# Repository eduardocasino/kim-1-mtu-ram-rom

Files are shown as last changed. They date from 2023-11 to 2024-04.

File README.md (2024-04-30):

# KIM-1 RAM/ROM Expansion Board for the MTU Backplane

## **WARNING**

**ALTHOUGH THE REV. 3 SEEMS TO BE WORKING SO FAR, IT STILL NEEDS MORE TESTING. USE AT YOUR OWN RISK!!!**

If you ordered the first or second revision PCB, please see the "Rev. 1 Fix" and/or "Rev. 2 Fix" sections below.

## About

This is a highly configurable RAM/ROM expansion for MTU backplanes, like the one in the original K-1005 card file, my [expansion card](https://github.com/eduardocasino/kim-1-mtu-expansion-card) or my buffered motherboard.

WARNING: This design has not been tested yet. Use at your own risk!

## Characteristics

* Switchable 0000-03FF systen RAM replacement
* Switchable 0400-13FF RAM
* Switchable system ROM replacement (needs a small modification to the MTU boards to disable the DECEN line)
* 4 selectable ROM sets
* Enough room to place a ZIF socket for the ROM
* Switchable 4K RAM/ROM areas from 2000 to FFFF
* Configurable interrupt vectors to the top of any of the 4K chunks.
* Max. 1 TTL load on the bus, so it will work nicely on unbuffered backplanes

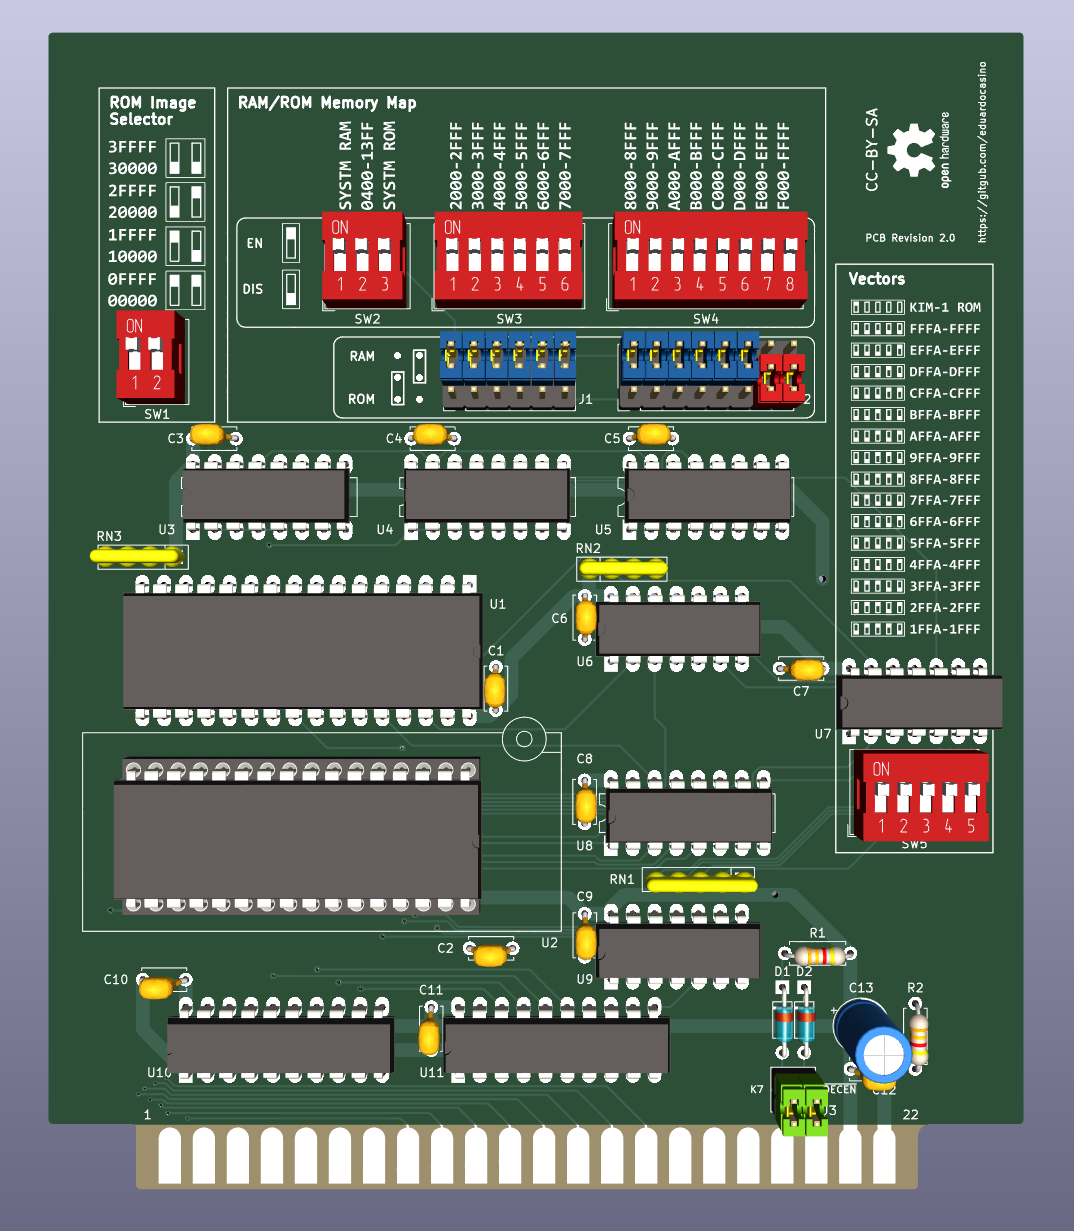
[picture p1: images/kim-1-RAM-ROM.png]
components

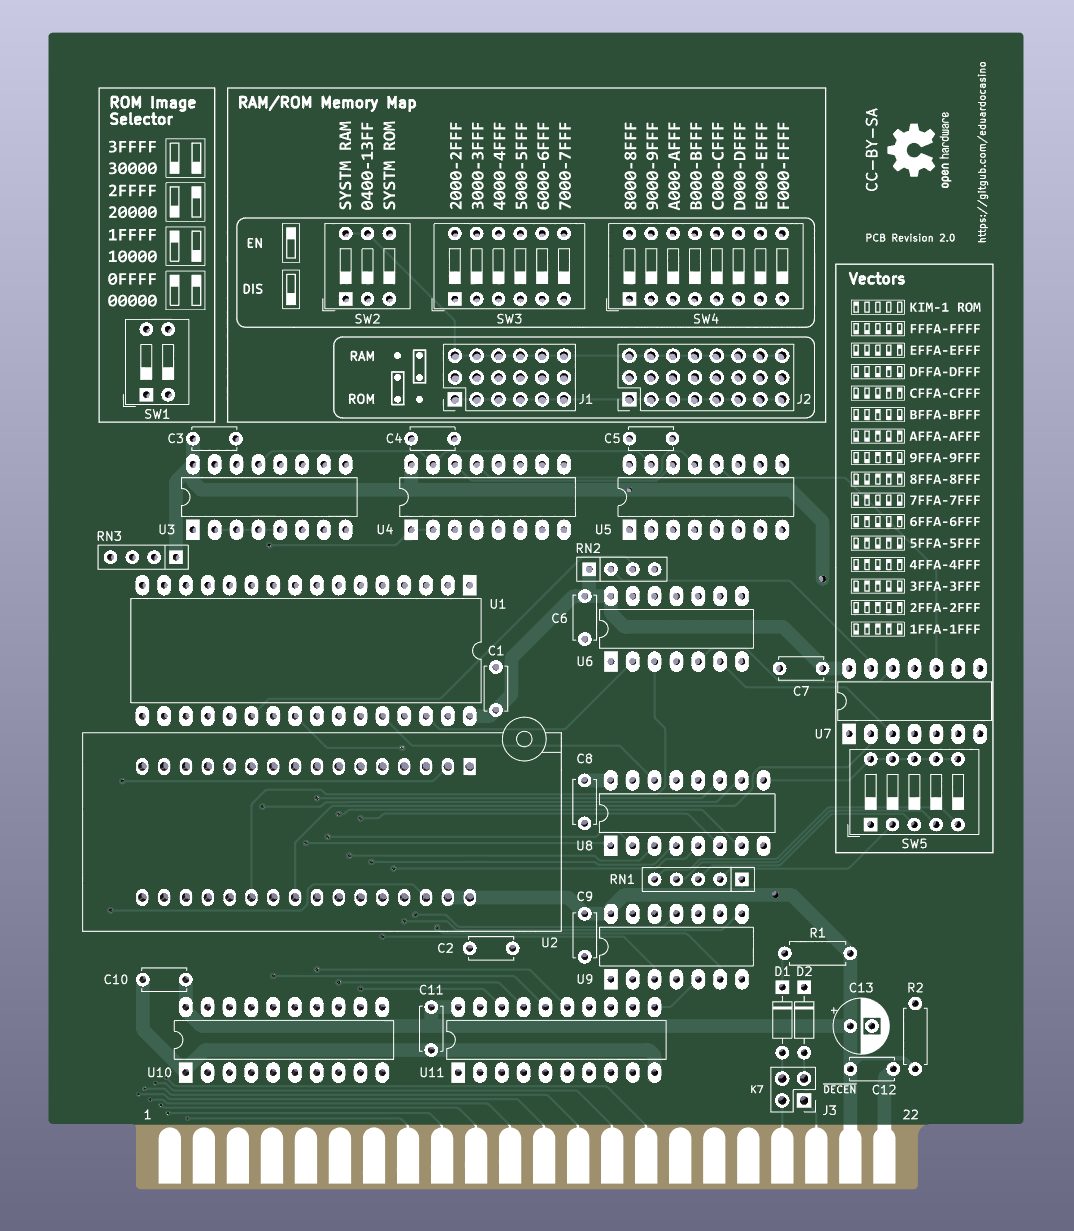
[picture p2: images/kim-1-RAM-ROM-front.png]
front

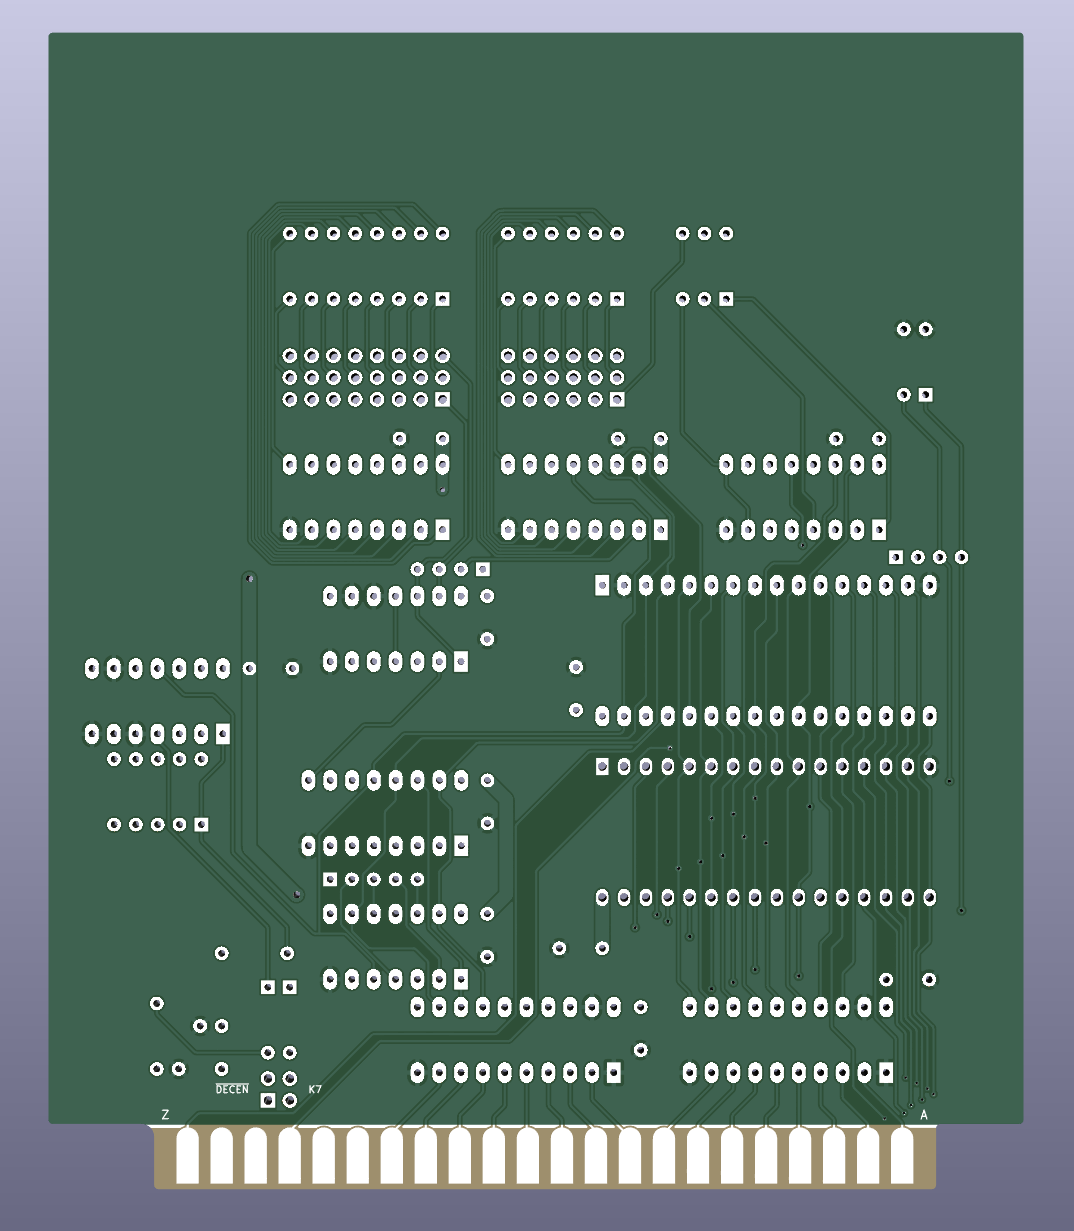
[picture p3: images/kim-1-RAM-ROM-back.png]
back


## Licensing

This is a personal project that I am sharing in case it is of interest to any retrocomputing enthusiast and all the information in this repository is provided "as is", without warranty of any kind. I am not liable for any damages that may occur, whether it be to individuals, objects, KIM-1 computers, kittens or any other pets. **It should also be noted that everything in this repository is a work in progress, has not been tested and may contain errors, therefore anyone who chooses to use it does so at their own risk**.



This work is licensed under a [Creative Commons Attribution-ShareAlike 4.0 International License](http://creativecommons.org/licenses/by-sa/4.0/).

See the LICENSE.md file for details.

## Rev. 2 Fix

Replacing the system RAM (0x0000-0x03FF) does not work reliably with the revision 2 PCB.

There is a simple fix with a couple of bodges:

Using a cutter, carefully cut the tracks that joins pin 24 of U1 and pin 16 of U2:

step1

On the back side, cut the spoke at pin 24 of U1 (not strictly needed, but it is better to not have that copper island attached to the pin) and the track that joins pin 29 of U1 and pad 'V' of the edge connector:

step2

Finally, solder these two wires:

step3

## Rev. 1 Fix

If you built revision 1 of this board, you may have found out that the 0400-13FF RAM does not work with the [buffered motherboard](https://github.com/eduardocasino/kim-1-mtu-motherboard). It works fine with the [passive expansion board](https://github.com/eduardocasino/kim-1-mtu-expansion-card) and it should also work in a real MTU cabinet (See [Issue #1](https://github.com/eduardocasino/kim-1-mtu-ram-rom/issues/1))

You can perform this very simple bodge on the the PCB:

Using a cutter, carefully cut the track that joins pins 1 and 4 of U6 on the front side of the PCB:

step1

Now on the back side, cut these spokes at pins 12 and 13 of the same IC:

step2

Finally, solder these three wires:

step3

## Changelog
#### 30/04/2024
* Release Rev. 3
* Fix replacing system RAM
#### 28/01/2024
* Release Rev. 2
* Fix [Issue #1](https://github.com/eduardocasino/kim-1-mtu-ram-rom/issues/1)
* Add new option for replacing system RAM
* Make some more space for the ZIF socket lever
* Add instructions to fix Rev. 1 boards.
#### 05/01/2024
* Minor silkscreen modifications
#### 26/11/2023
* Remove useless option to support the MTU floppy controller boot prom
* Simplify design a bit
#### 24/11/2023
* Add option to support the MTU floppy controller boot prom
* Minor silkscreen update

## Acknowledgements

* This design is based on late Bob Applegate's [60K RAM/ROM card](https://www.corshamtech.com/product/kim-1-60k-rameprom-board/)

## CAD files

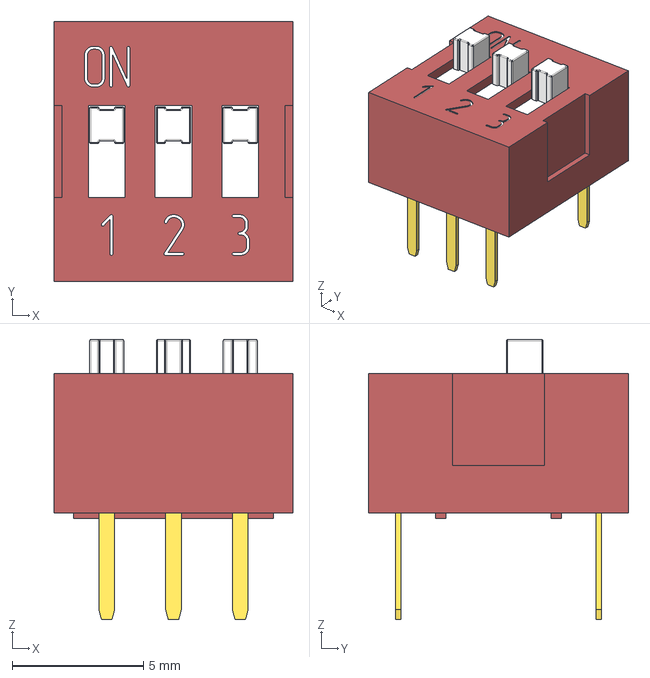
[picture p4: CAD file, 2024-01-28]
3dmodels/DS1040-03 (DIP_switch).stp
9.08 x 9.90 x 10.7 mm

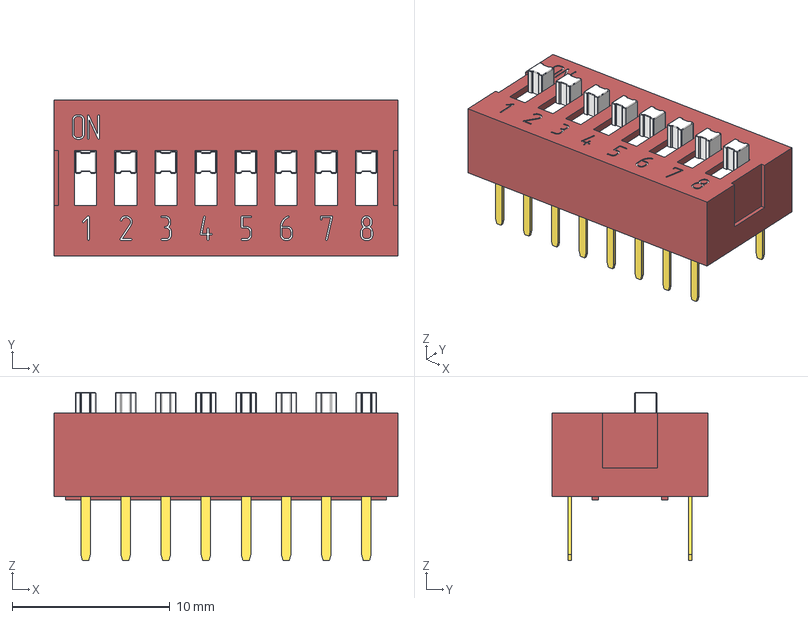
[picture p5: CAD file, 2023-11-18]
3dmodels/DS1040-08 (DIP_switch).stp
21.8 x 9.90 x 10.7 mm

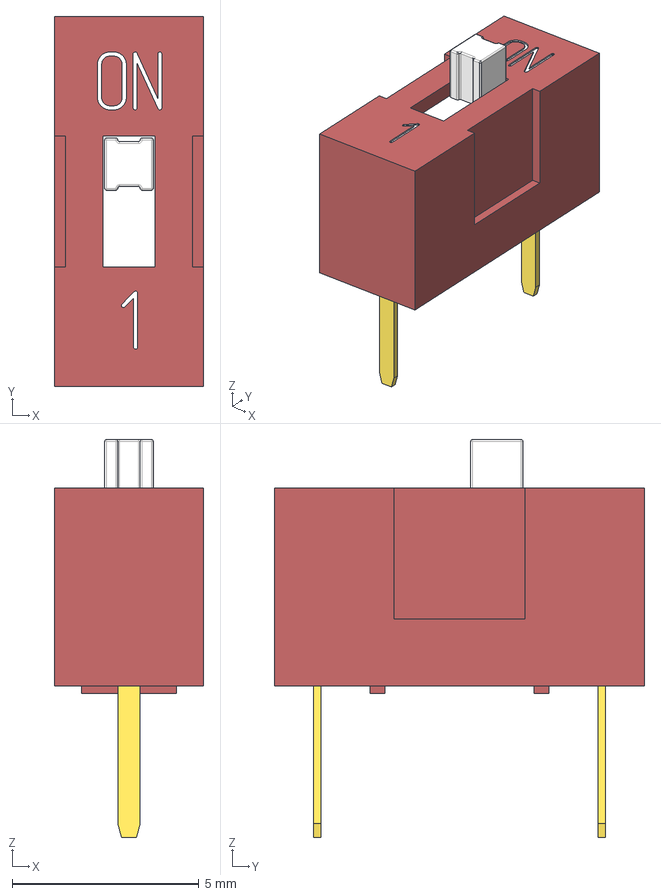
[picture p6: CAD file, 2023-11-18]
3dmodels/DS1040-01 (DIP_switch).stp
4.00 x 9.90 x 10.7 mm

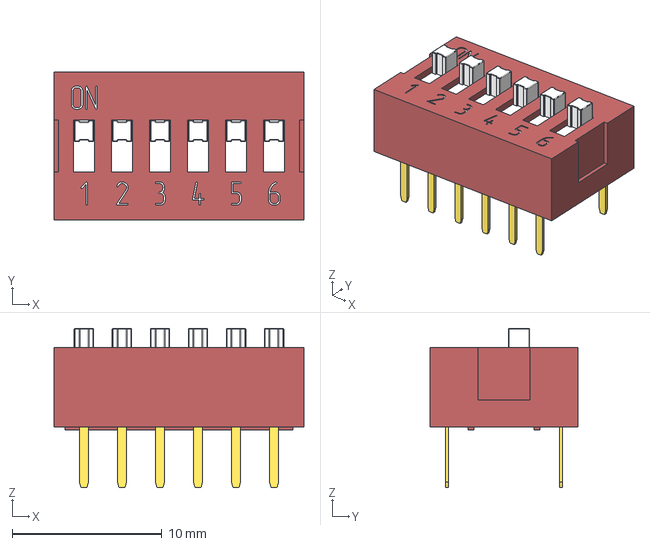
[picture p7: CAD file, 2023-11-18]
3dmodels/DS1040-06 (DIP_switch).stp
16.7 x 9.90 x 10.7 mm

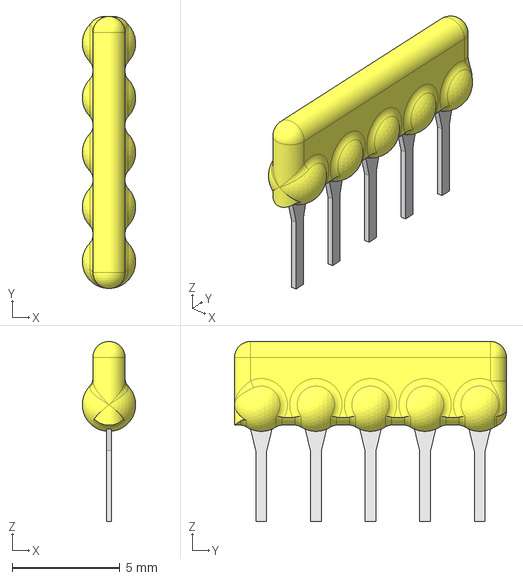
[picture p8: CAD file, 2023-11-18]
3dmodels/resistor_array_4.step
2.48 x 12.7 x 8.38 mm

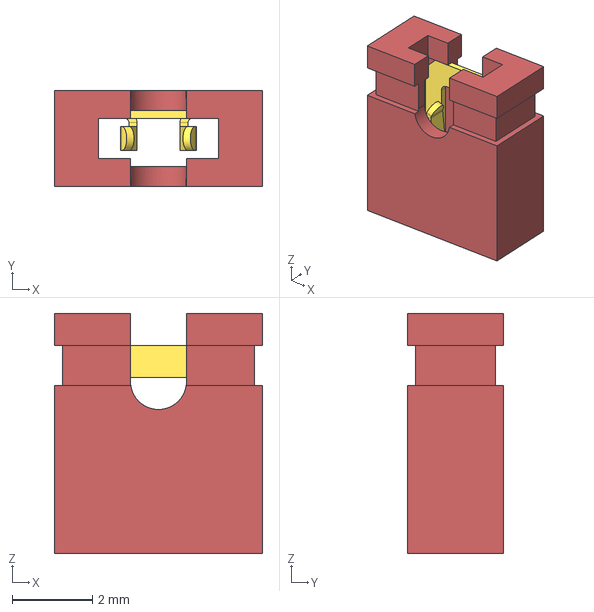
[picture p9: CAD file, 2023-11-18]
3dmodels/Jumper-red.step
5.20 x 2.40 x 6.00 mm

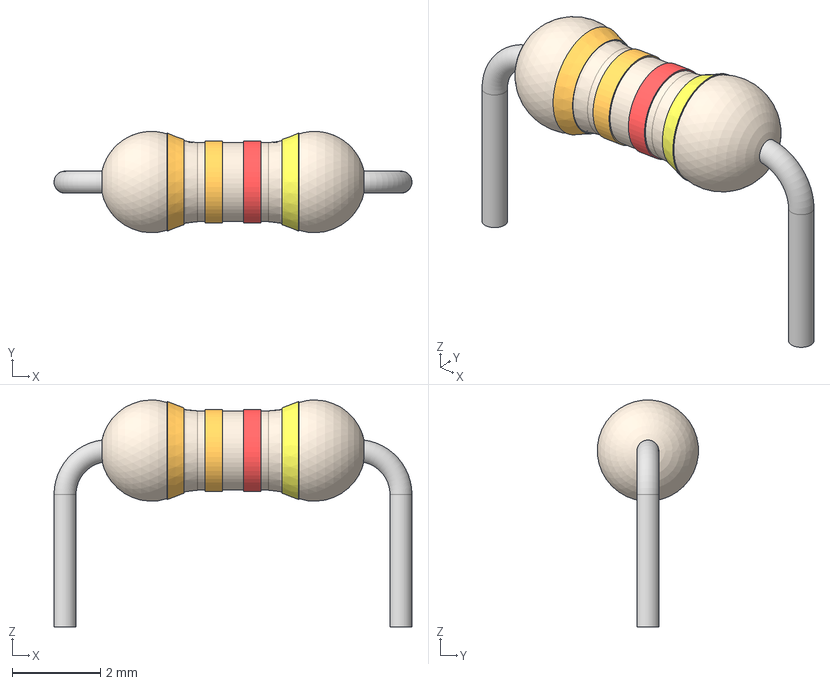
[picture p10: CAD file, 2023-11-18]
3dmodels/res-1_4w-3K3-7.62mm.step
8.12 x 2.29 x 5.14 mm
Resistor-body
Ring-1
Ring-2
Ring-3
Ring-4
pins

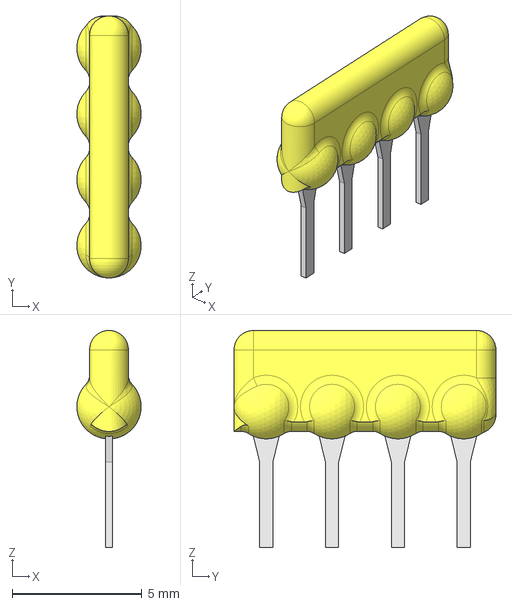
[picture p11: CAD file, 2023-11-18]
3dmodels/resistor_array_3.step
2.48 x 10.1 x 8.38 mm

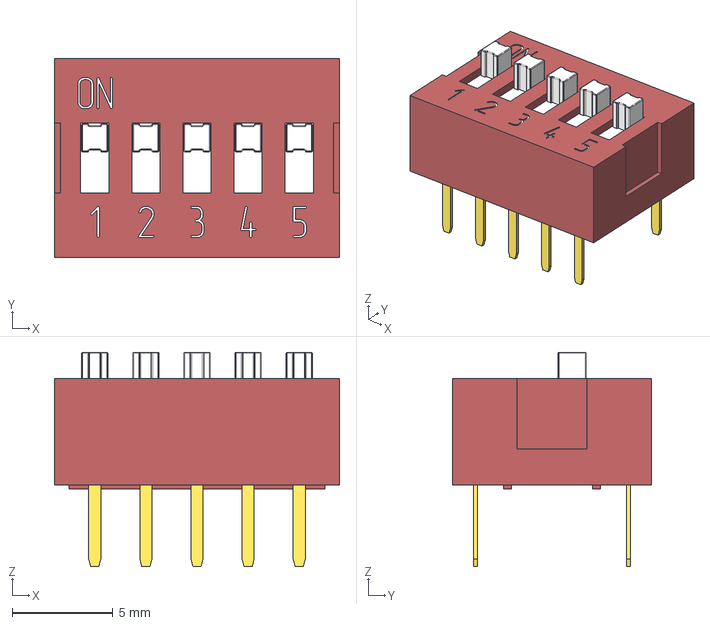
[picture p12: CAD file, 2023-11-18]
3dmodels/DS1040-05 (DIP_switch).stp
14.2 x 9.90 x 10.7 mm

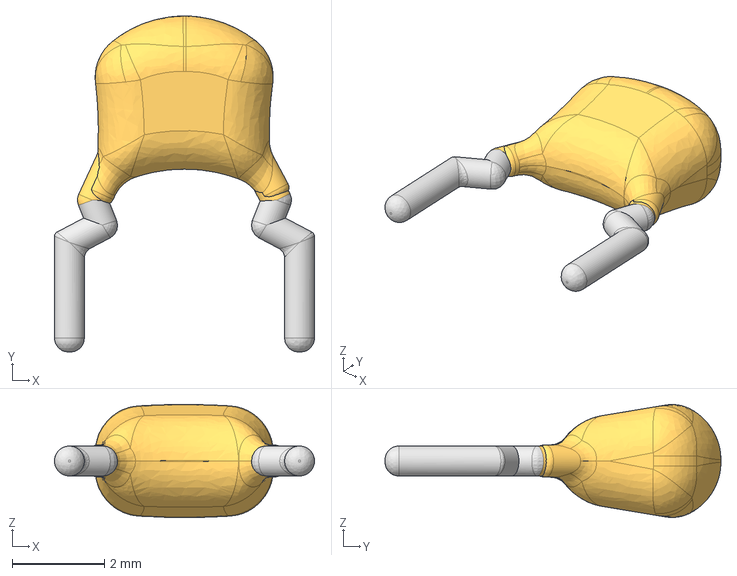
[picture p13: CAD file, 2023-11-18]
3dmodels/Ceramic Cap, 5mm lead spacing, 4mm width, and 5.5mm tall, v4 v2.step
5.65 x 7.30 x 2.46 mm

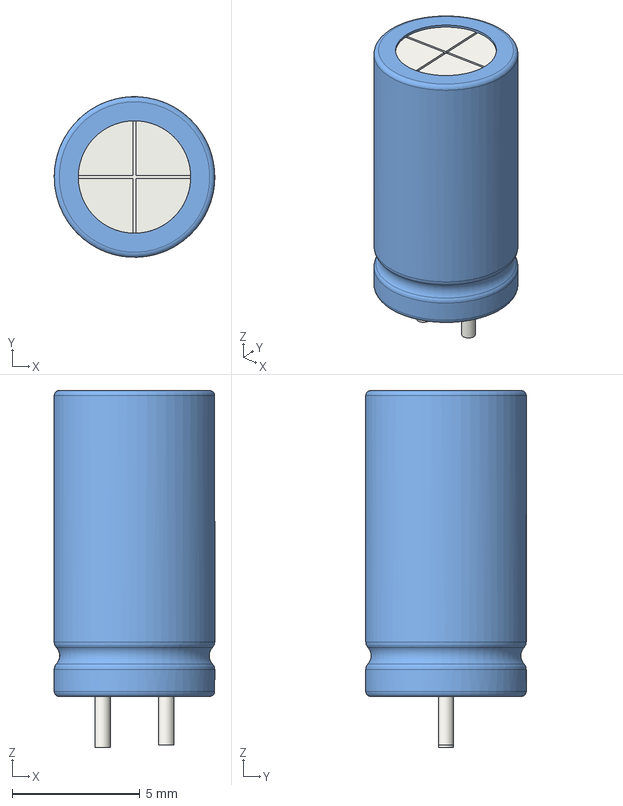
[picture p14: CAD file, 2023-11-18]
3dmodels/C_Radial_D6.3mm_H12.0mm_P2.50mm.step
6.30 x 6.30 x 14.0 mm
02c9364b-712a-11ee-b682-09d101288ea8_part
02c9364c-712a-11ee-b682-09d101288ea8_part
02c9364d-712a-11ee-b682-09d101288ea8_part
02c9364e-712a-11ee-b682-09d101288ea8_part
02c9364f-712a-11ee-b682-09d101288ea8_part

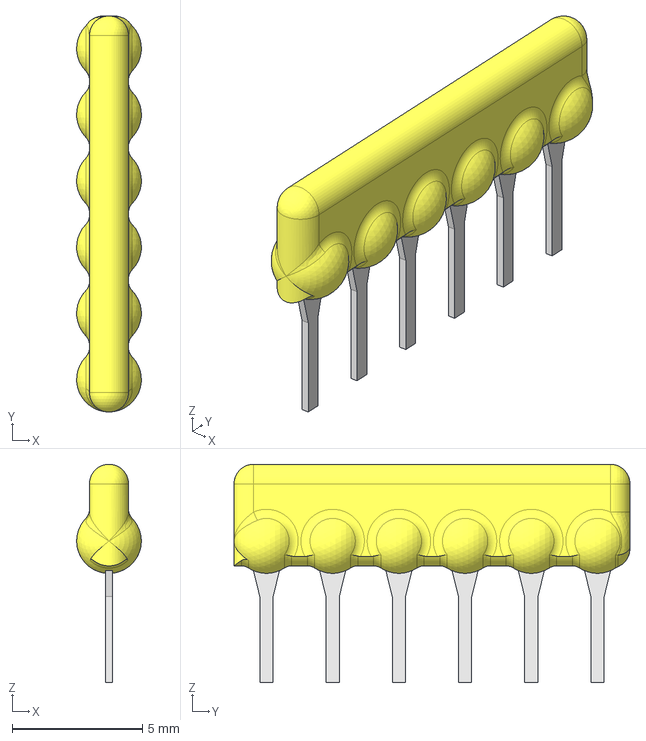
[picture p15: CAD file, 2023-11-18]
3dmodels/resistor_array_5.step
2.48 x 15.2 x 8.38 mm

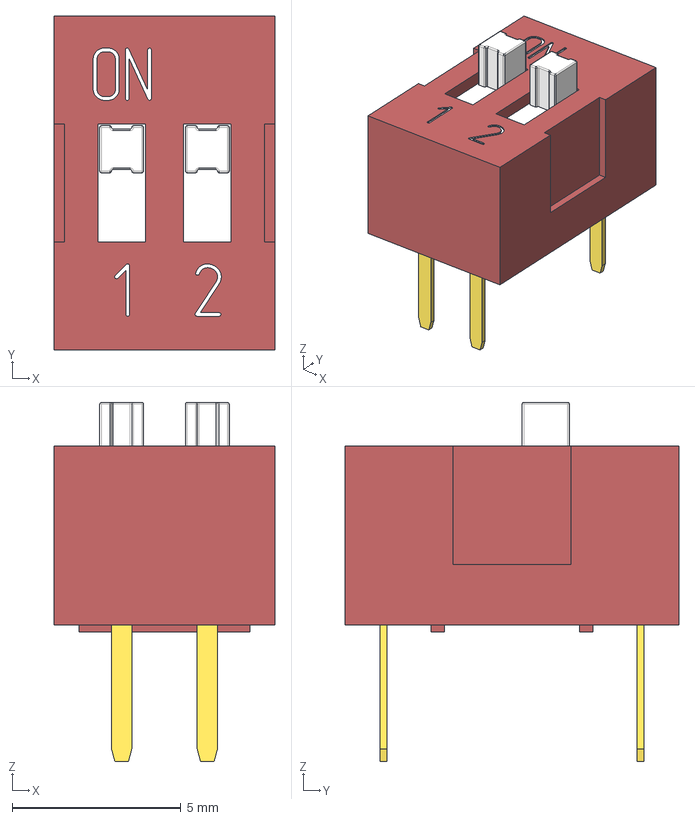
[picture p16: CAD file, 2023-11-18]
3dmodels/DS1040-02 (DIP_switch).stp
6.54 x 9.90 x 10.7 mm

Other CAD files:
3dmodels/Jumper-blue.step
3dmodels/Jumper-green.step

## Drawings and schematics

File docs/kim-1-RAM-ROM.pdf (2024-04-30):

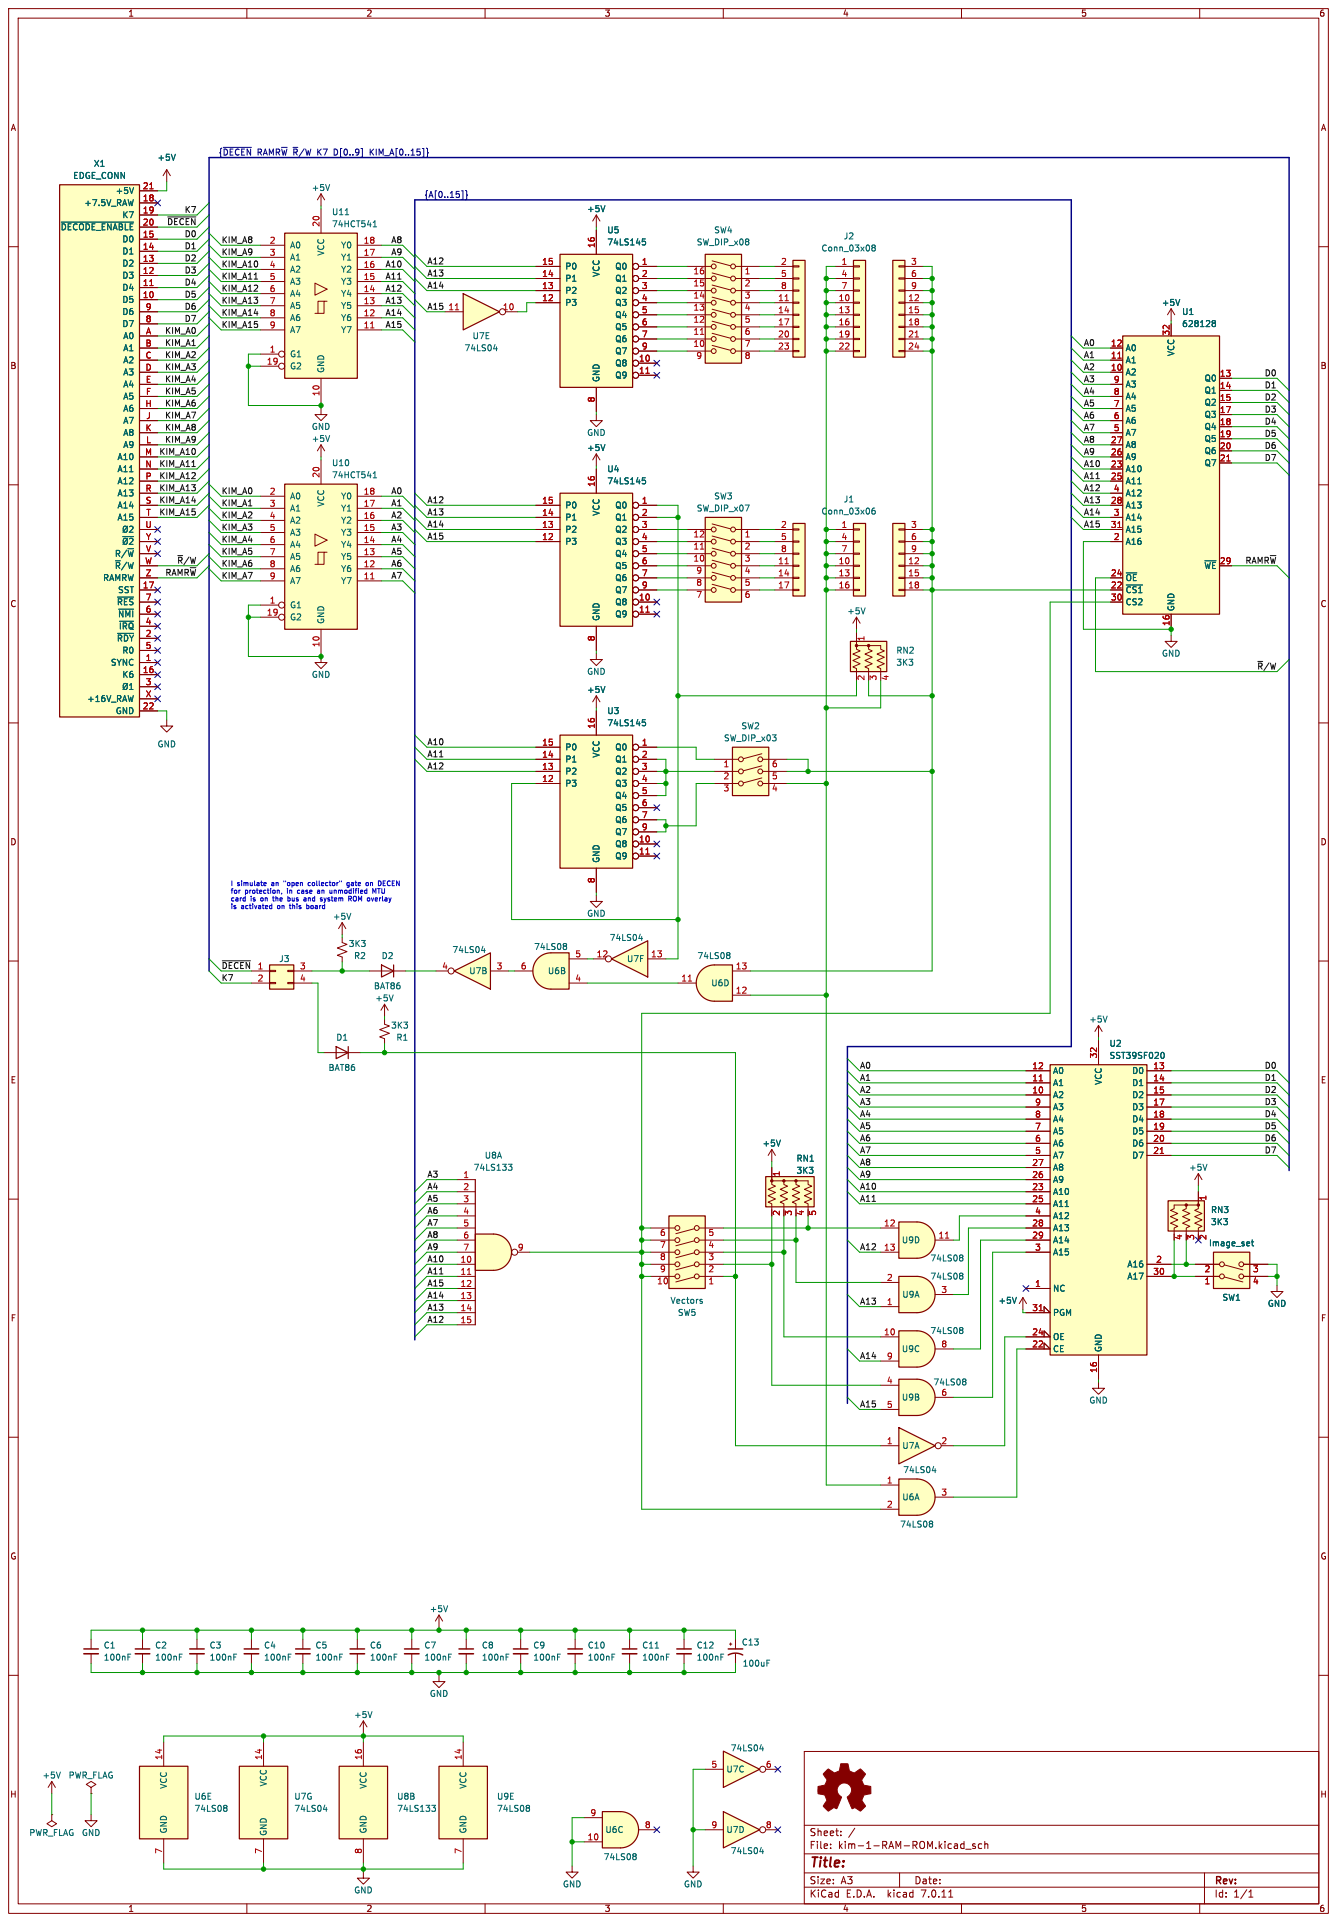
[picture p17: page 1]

8 Q7 9 U2SST39SF020 GND 16 VCC 32 NC 1 A2 10 A1 11 A0 12 D0 13 D1 14 D2 15 D3 17 D4 18 D5 19 A16 2 D6 20 D7 21 CE 22 A10 23 OE 24 A11 25 A9 26 A8 27 A13 28 A14 29 A15 3 A17 30 PGM 31 A12 4 A7 5 A6 6 A5 7 A4 8 A3 9 SW1

card is on the bus and system ROM overlay

Id: 1/1 Title: File: kim-1-RAM-ROM.kicad_sch Sheet: /

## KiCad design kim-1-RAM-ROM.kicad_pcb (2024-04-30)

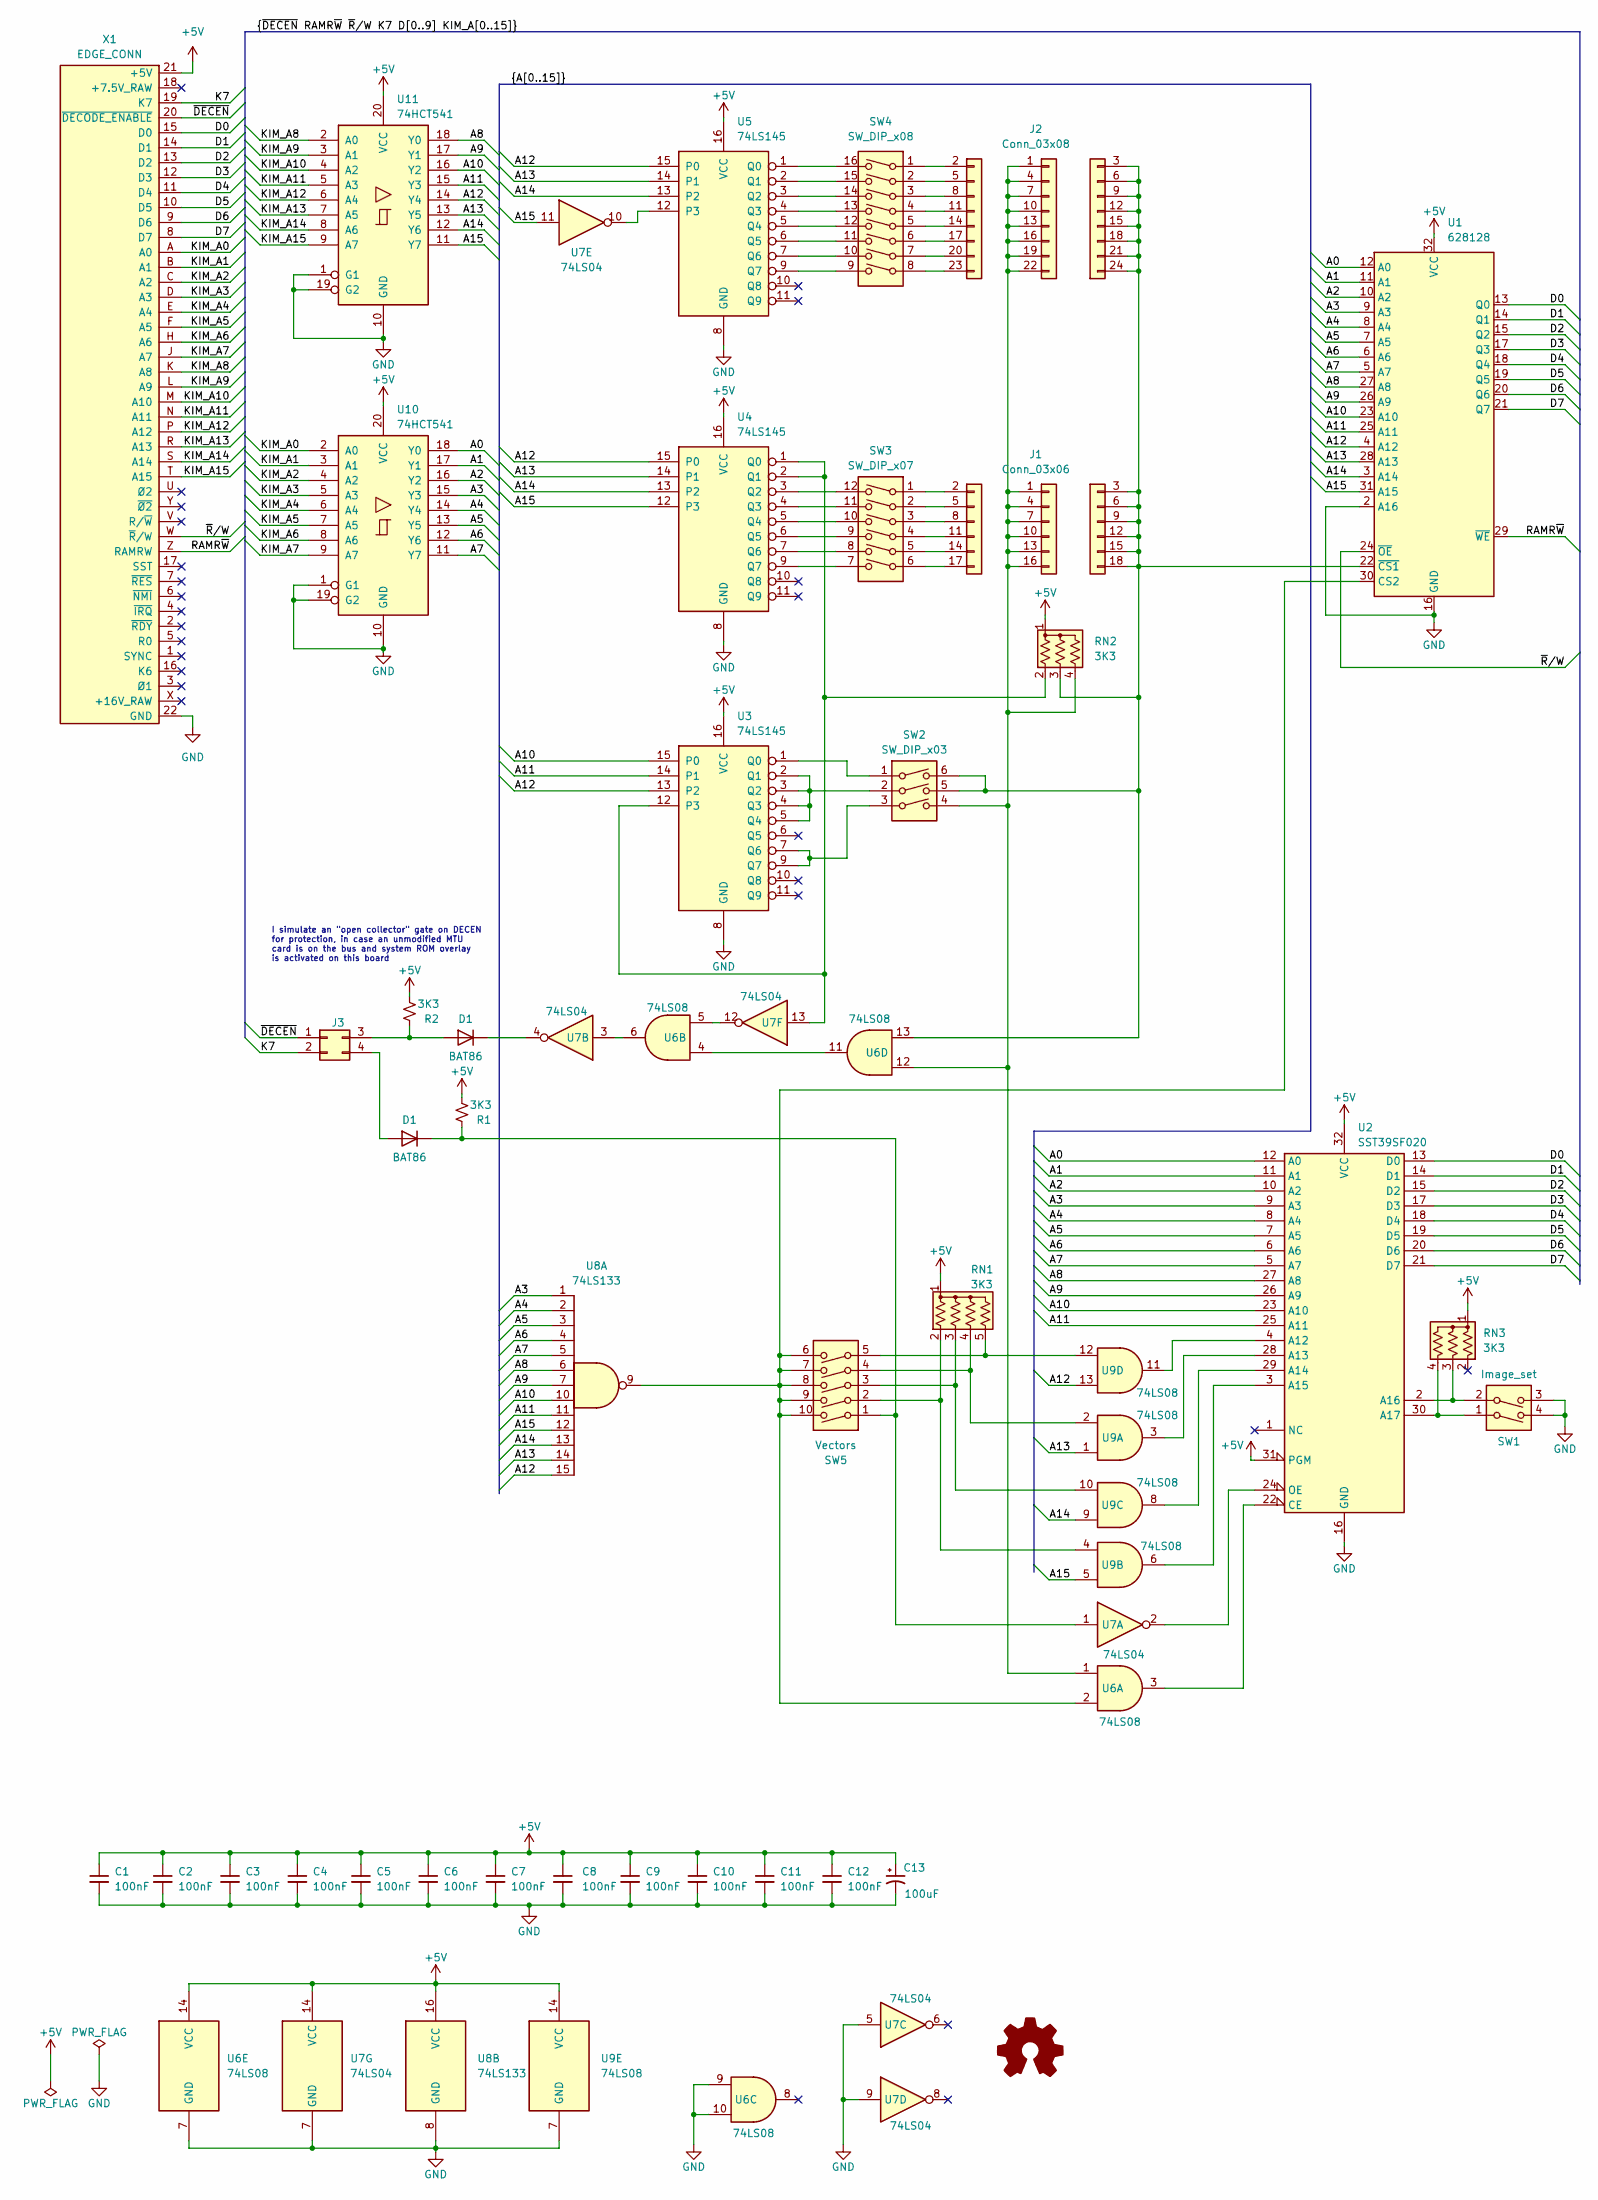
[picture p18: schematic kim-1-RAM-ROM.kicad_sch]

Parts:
C1, C2, C3, C4, C5, C6, C7, C8, C9, C10, C11, C12: 100nF; C_Disc_D5.0mm_W2.5mm_P5.00mm
C13: 100uF; CP_Radial_D6.3mm_P2.50mm
D1: BAT86; D_DO-35_SOD27_P7.62mm_Horizontal
J1: Conn_03x06; PinHeader_3x06_P2.54mm_Vertical
J2: Conn_03x08; PinHeader_3x08_P2.54mm_Vertical
J3: Conn_02x08_Counter_Clockwise; PinHeader_2x02_P2.54mm_Vertical
R1, R2: 3K3; R_Axial_DIN0207_L6.3mm_D2.5mm_P7.62mm_Horizontal
RN1: 3K3; R_Array_SIP5
RN2, RN3: 3K3; R_Array_SIP4
SW1: Image_set; SW_DIP_SPSTx02_Slide_9.78x7.26mm_W7.62mm_P2.54mm
SW2: SW_DIP_x03; SW_DIP_SPSTx03_Slide_9.78x9.8mm_W7.62mm_P2.54mm
SW3: SW_DIP_x07; SW_DIP_SPSTx06_Slide_9.78x17.42mm_W7.62mm_P2.54mm
SW4: SW_DIP_x08; SW_DIP_SPSTx08_Slide_9.78x22.5mm_W7.62mm_P2.54mm
SW5: Vectors; SW_DIP_SPSTx05_Slide_9.78x14.88mm_W7.62mm_P2.54mm
U1: 628128; DIP-32_W15.24mm_LongPads
U2: SST39SF020; DIP_Socket-32_W11.9_W12.7_W15.24_W17.78_W18.5_3M_232-1285-0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
U3, U4, U5: 74LS145; DIP-16_W7.62mm_LongPads
U6, U9: 74LS08; DIP-14_W7.62mm_LongPads
U7: 74LS04; DIP-14_W7.62mm_LongPads
U8: 74LS133; DIP-16_W7.62mm_LongPads
U10, U11: 74HCT541; DIP-20_W7.62mm_LongPads
X1: EDGE_CONN

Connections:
+5V: C1.1, C2.1, C3.1, C4.1, C5.1, C6.1, C7.1, C8.1, C9.1, C10.1, C11.1, C12.1, C13.1, R1.2, R2.2, RN1.1 (common), RN2.1 (common), RN3.1 (common), U1.32 (VCC), U2.31 (PGM), U2.32 (VCC), U3.16 (VCC), U4.16 (VCC), U5.16 (VCC), U6.14 (VCC), U7.14 (VCC), U8.16 (VCC), U9.14 (VCC), U10.20 (VCC), U11.20 (VCC), X1.21 (+5V)
/A0: U1.12 (A0), U2.12 (A0), U10.18 (Y0)
/A1: U1.11 (A1), U2.11 (A1), U10.17 (Y1)
/A2: U1.10 (A2), U2.10 (A2), U10.16 (Y2)
/A3: U1.9 (A3), U2.9 (A3), U8.1, U10.15 (Y3)
/A4: U1.8 (A4), U2.8 (A4), U8.2, U10.14 (Y4)
/A5: U1.7 (A5), U2.7 (A5), U8.3, U10.13 (Y5)
/A6: U1.6 (A6), U2.6 (A6), U8.4, U10.12 (Y6)
/A7: U1.5 (A7), U2.5 (A7), U8.5, U10.11 (Y7)
/A8: U1.27 (A8), U2.27 (A8), U8.6, U11.18 (Y0)
/A9: U1.26 (A9), U2.26 (A9), U8.7, U11.17 (Y1)
/A10: U1.23 (A10), U2.23 (A10), U3.15 (P0), U8.10, U11.16 (Y2)
/A11: U1.25 (A11), U2.25 (A11), U3.14 (P1), U8.11, U11.15 (Y3)
/A12: U1.4 (A12), U3.13 (P2), U4.15 (P0), U5.15 (P0), U8.15, U9.13, U11.14 (Y4)
/A13: U1.28 (A13), U4.14 (P1), U5.14 (P1), U8.14, U9.1, U11.13 (Y5)
/A14: U1.3 (A14), U4.13 (P2), U5.13 (P2), U8.13, U9.9, U11.12 (Y6)
/A15: U1.31 (A15), U4.12 (P3), U7.11, U8.12, U9.5, U11.11 (Y7)
/D0: U1.13 (Q0), U2.13 (D0), X1.15 (D0)
/D1: U1.14 (Q1), U2.14 (D1), X1.14 (D1)
/D2: U1.15 (Q2), U2.15 (D2), X1.13 (D2)
/D3: U1.17 (Q3), U2.17 (D3), X1.12 (D3)
/D4: U1.18 (Q4), U2.18 (D4), X1.11 (D4)
/D5: U1.19 (Q5), U2.19 (D5), X1.10 (D5)
/D6: U1.20 (Q6), U2.20 (D6), X1.9 (D6)
/D7: U1.21 (Q7), U2.21 (D7), X1.8 (D7)
/K7: J3.2, X1.19 (K7)
/KIM_A0: U10.2 (A0), X1.A (A0)
/KIM_A1: U10.3 (A1), X1.B (A1)
/KIM_A2: U10.4 (A2), X1.C (A2)
/KIM_A3: U10.5 (A3), X1.D (A3)
/KIM_A4: U10.6 (A4), X1.E (A4)
/KIM_A5: U10.7 (A5), X1.F (A5)
/KIM_A6: U10.8 (A6), X1.H (A6)
/KIM_A7: U10.9 (A7), X1.J (A7)
/KIM_A8: U11.2 (A0), X1.K (A8)
/KIM_A9: U11.3 (A1), X1.L (A9)
/KIM_A10: U11.4 (A2), X1.M (A10)
/KIM_A11: U11.5 (A3), X1.N (A11)
/KIM_A12: U11.6 (A4), X1.P (A12)
/KIM_A13: U11.7 (A5), X1.R (A13)
/KIM_A14: U11.8 (A6), X1.S (A14)
/KIM_A15: U11.9 (A7), X1.T (A15)
/RAMR~W: U1.29 (~WE), X1.Z (RAMRW)
/~DECEN: J3.1, X1.20 (~DECODE_ENABLE)
/~R/W: U1.24 (~OE), X1.W (~R/W)
GND: C1.2, C2.2, C3.2, C4.2, C5.2, C6.2, C7.2, C8.2, C9.2, C10.2, C11.2, C12.2, C13.2, SW1.3, SW1.4, U1.2 (A16), U1.16 (GND), U2.16 (GND), U3.8 (GND), U4.8 (GND), U5.8 (GND), U6.7 (GND), U6.9, U6.10, U7.5, U7.7 (GND), U7.9, U8.8 (GND), U9.7 (GND), U10.1 (G1), U10.10 (GND), U10.19 (G2), U11.1 (G1), U11.10 (GND), U11.19 (G2), X1.22 (GND)
unnamed: J1.1, J1.4, J1.7, J1.10, J1.13, J1.16, J2.1, J2.4, J2.7, J2.10, J2.13, J2.16, J2.19 (Pin_º9), J2.22, RN2.4 (R3), SW2.4, U6.1, U6.12
unnamed: J1.2, SW3.1
unnamed: J1.5, SW3.2
unnamed: J1.8, SW3.3
unnamed: J1.11, SW3.4
unnamed: J1.3, J1.6, J1.9, J1.12, J1.15, J1.18, J2.3, J2.6, J2.9, J2.12, J2.15, J2.18, J2.21, J2.24, RN2.3 (R2), SW2.5, SW2.6, U1.22 (~CS1), U6.13
unnamed: J1.14, SW3.5
unnamed: J1.17, SW3.6
unnamed: J2.2, SW4.1
unnamed: J2.5, SW4.2
unnamed: J2.8, SW4.3
unnamed: J2.11, SW4.4
unnamed: J2.14, SW4.5
unnamed: J2.17, SW4.6
unnamed: J2.20, SW4.7
unnamed: J2.23, SW4.8
unnamed: RN1.2 (R1), SW5.2, U9.4
unnamed: RN1.3 (R2), SW5.3, U9.10
unnamed: RN1.4 (R3), SW5.4, U9.2
unnamed: RN1.5 (R4), SW5.5, U9.12
unnamed: RN2.2 (R1), U3.12 (P3), U4.1 (Q0), U4.2 (Q1), U7.13
unnamed: RN3.3 (R2), SW1.2, U2.2 (A16)
unnamed: RN3.4 (R3), SW1.1, U2.30 (A17)
unnamed: SW5.6, SW5.7, SW5.8, SW5.9, SW5.10, U1.30 (CS2), U6.2, U8.9
unnamed: U2.4 (A12), U9.11
unnamed: U2.28 (A13), U9.3
unnamed: U2.29 (A14), U9.8
unnamed: U2.3 (A15), U9.6
unnamed: U2.22 (CE), U6.3
unnamed: U2.24 (OE), U7.2
unnamed: SW2.1, U3.1 (Q0)
unnamed: SW2.2, U3.2 (Q1), U3.3 (Q2), U3.4 (Q3), U3.5 (Q4)
unnamed: SW2.3, U3.7 (Q6), U3.9 (Q7)
unnamed: SW3.12, U4.3 (Q2)
unnamed: SW3.11, U4.4 (Q3)
unnamed: SW3.10, U4.5 (Q4)
unnamed: SW3.9, U4.6 (Q5)
unnamed: SW3.8, U4.7 (Q6)
unnamed: SW3.7, U4.9 (Q7)
unnamed: U5.12 (P3), U7.10
unnamed: SW4.16, U5.1 (Q0)
unnamed: SW4.15, U5.2 (Q1)
unnamed: SW4.14, U5.3 (Q2)
unnamed: SW4.13, U5.4 (Q3)
unnamed: SW4.12, U5.5 (Q4)
unnamed: SW4.11, U5.6 (Q5)
unnamed: SW4.10, U5.7 (Q6)
unnamed: SW4.9, U5.9 (Q7)
unnamed: U6.5, U7.12
unnamed: U6.6, U7.3
unnamed: U6.4, U6.11

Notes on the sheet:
I simulate an "open collector" gate on DECEN for protection, in case an unmodified MTU card is on the bus and system ROM overlay is activated on this board

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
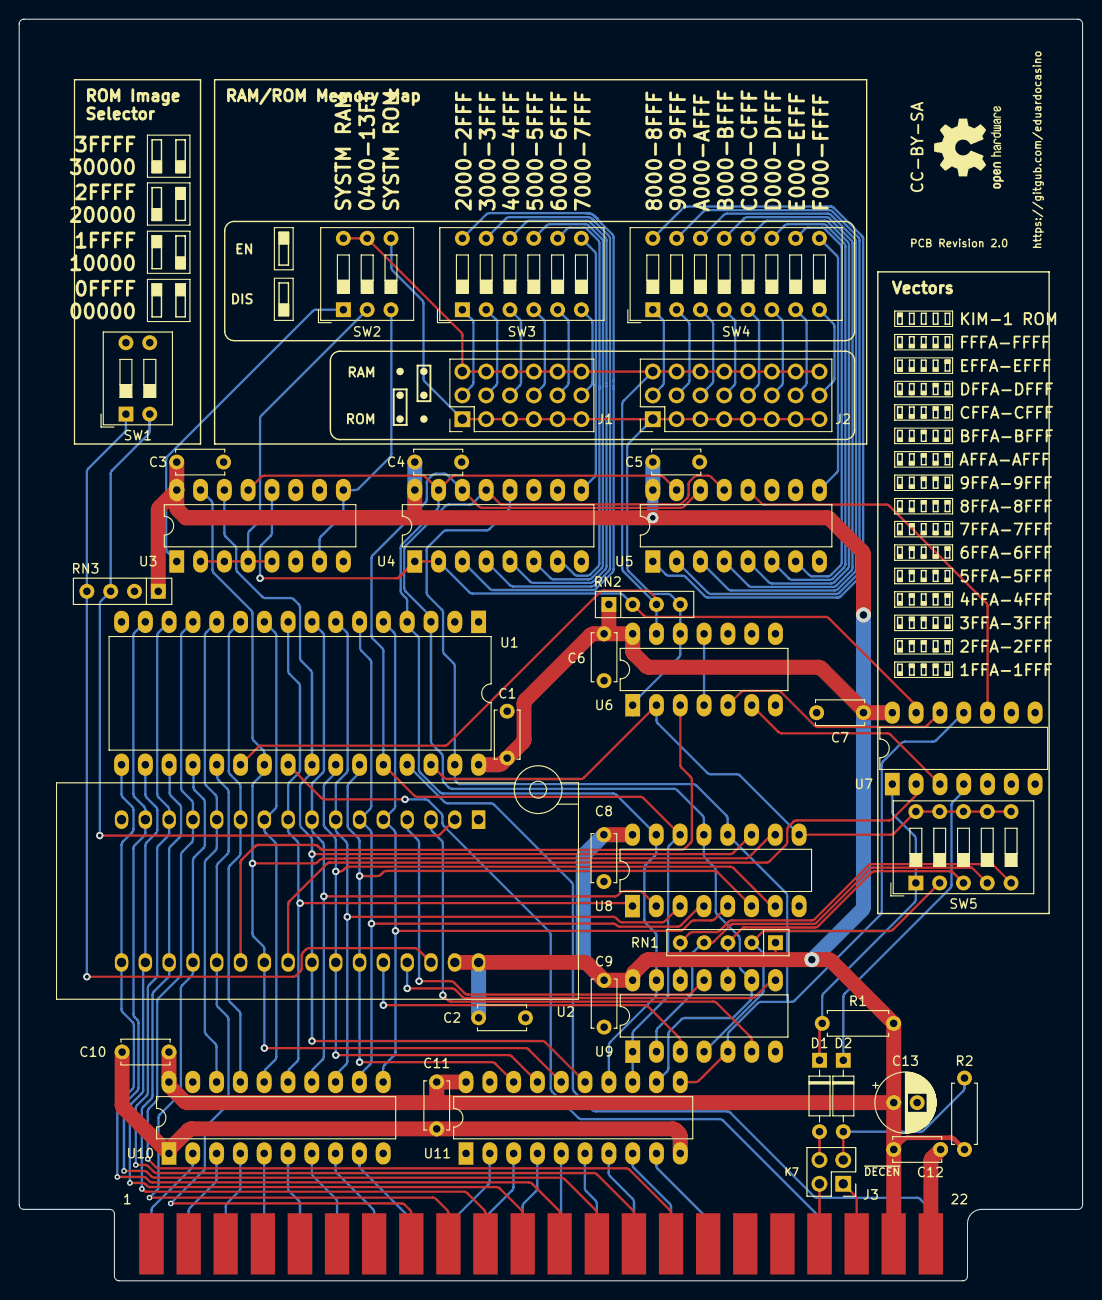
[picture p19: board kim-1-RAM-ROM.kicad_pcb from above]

Board: 2 copper layers, 113.5 x 134.6 mm, 40 parts (0 on the bottom side), 101 nets.

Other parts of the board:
D2: BAT86; D_DO-35_SOD27_P7.62mm_Horizontal

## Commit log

2023-11-24 Add option to support the MTU floppy controller boot prom
    [kim-1-RAM-ROM-B_Cu.gbr, kim-1-RAM-ROM-B_Mask.gbr, kim-1-RAM-ROM-B_Silkscreen.gbr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]
2023-11-24 Minor silkscreen changes
    [kim-1-RAM-ROM.kicad_pcb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]
2023-11-26 Remove useless switch and simplify design
    [kim-1-RAM-ROM-B_Cu.gbr, kim-1-RAM-ROM-B_Mask.gbr, kim-1-RAM-ROM-B_Silkscreen.gbr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]
2024-01-23 Add credits for DIP switches 3d models
2024-01-28 Release 2.0. Fixes issue #1
    [DS1040-03 (DIP_switch).stp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]
2024-04-30 Fix replacing system RAM
    [kim-1-RAM-ROM-B_Cu.gbr, kim-1-RAM-ROM-B_Mask.gbr, kim-1-RAM-ROM-B_Silkscreen.gbr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]

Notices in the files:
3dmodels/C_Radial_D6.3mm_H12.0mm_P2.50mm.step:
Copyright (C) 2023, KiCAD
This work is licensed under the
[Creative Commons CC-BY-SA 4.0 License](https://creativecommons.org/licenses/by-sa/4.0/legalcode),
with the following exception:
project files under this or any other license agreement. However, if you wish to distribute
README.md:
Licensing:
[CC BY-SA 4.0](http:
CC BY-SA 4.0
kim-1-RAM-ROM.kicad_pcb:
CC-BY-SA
